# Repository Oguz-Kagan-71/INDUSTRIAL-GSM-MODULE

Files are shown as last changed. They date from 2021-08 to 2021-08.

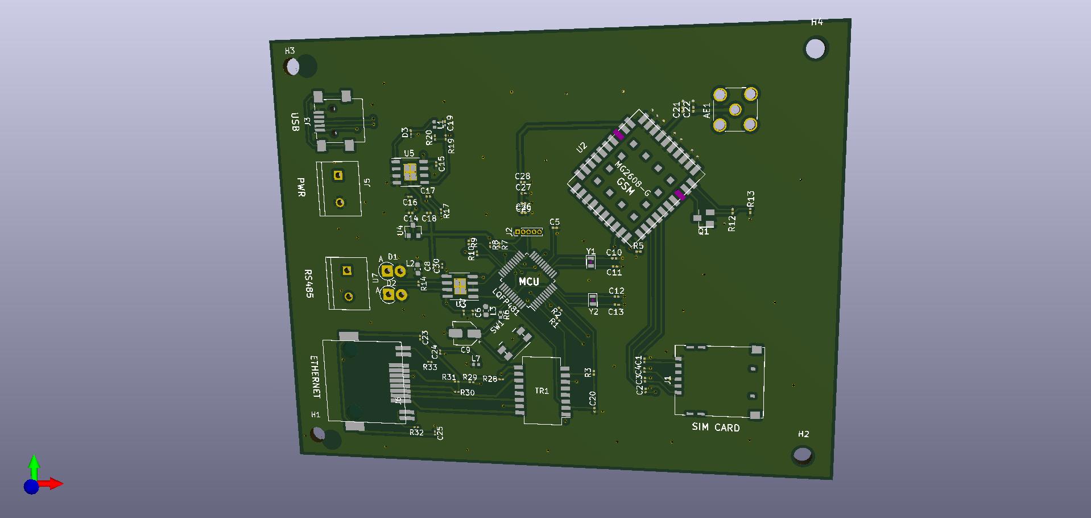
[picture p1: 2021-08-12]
gsm modem.jpg

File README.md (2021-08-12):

# INDUSTRIAL-GSM-MODULE
**PROJE KAZANIMLARI**
- Farklı amaca hizmet eden modüllerin datasheetini okuma
- Projeye uygun modül ve komponent seçimi
- Beslemelerde koruma amaçlı kullanılan kapasitör, endüktör, tvs diyot vb komponentlerin kullanımı
- PCB design edilen programda çoklu şematik pencere kullanımı, global label vb özelliklerin aktif kullanımı
- Kütüphanede olmayan komponentlerin şematik ve footprint kütüphanelerini datasheet bilgilerine göre oluşturup ekleme
- RS485 iletişim standartının ne olduğu ve hangi alanda kullanıldığı
- Transciever nedir ? Nasıl kullanılır ?
- Buck converter nedir ? Nasıl tasarlanır ?
- Yüksek voltaj kullanılan bir projede tasarım nasıl olmalıdır ? Regüle edilirken kullanılan komponentler nasıl konumlandırılmalıdır ?
- Konnektörler nasıl konumlandırılmalıdır ?
- Bağlantı kalınlıkları nasıl olmalıdır ?
- Anten bağlantısı nasıl olmalıdır ?
- Haberleşme bağlantıları nasıl olmalıdır ?
- GSM modülü nasıl çalışır ? Hangi amaca hizmet eder ?
- Modbus protokolü nedir ? Diğer haberleşme türlerinden farkı nedir ?
- 
-

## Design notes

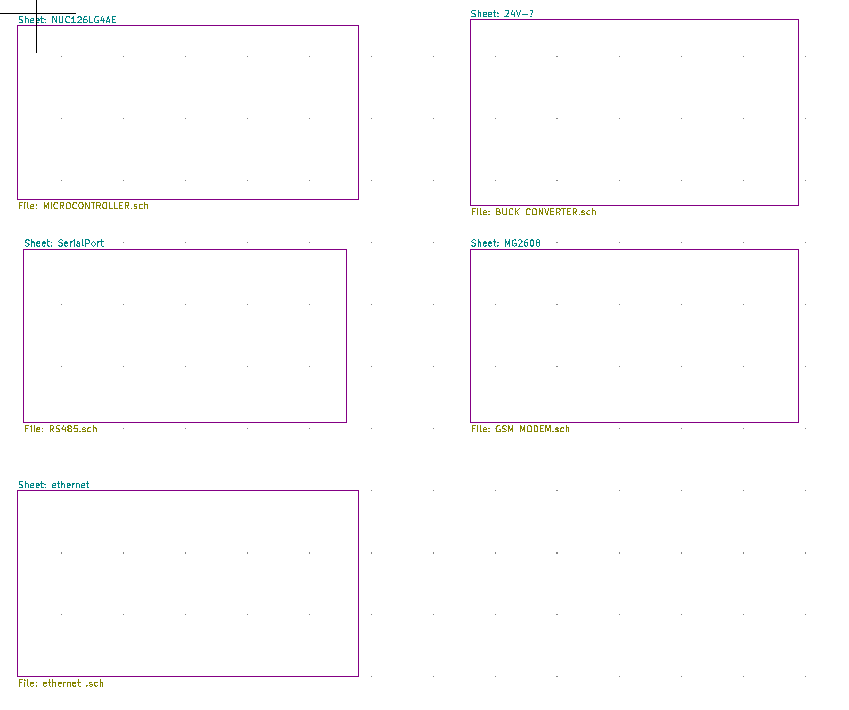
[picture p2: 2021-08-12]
Schematic.PNG

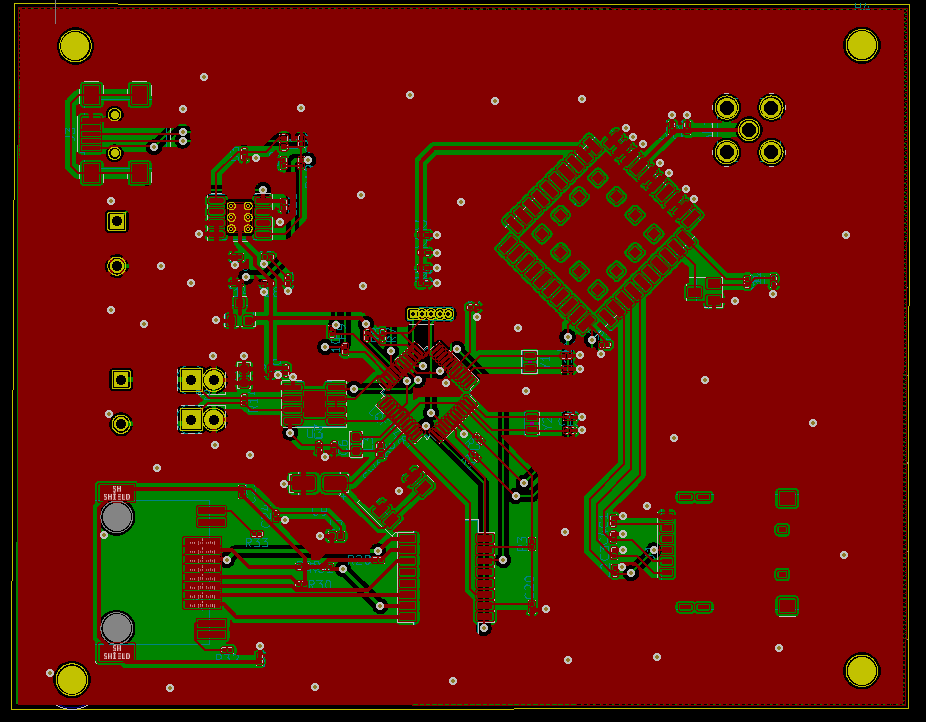
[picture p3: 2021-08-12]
gsm-pcb.PNG

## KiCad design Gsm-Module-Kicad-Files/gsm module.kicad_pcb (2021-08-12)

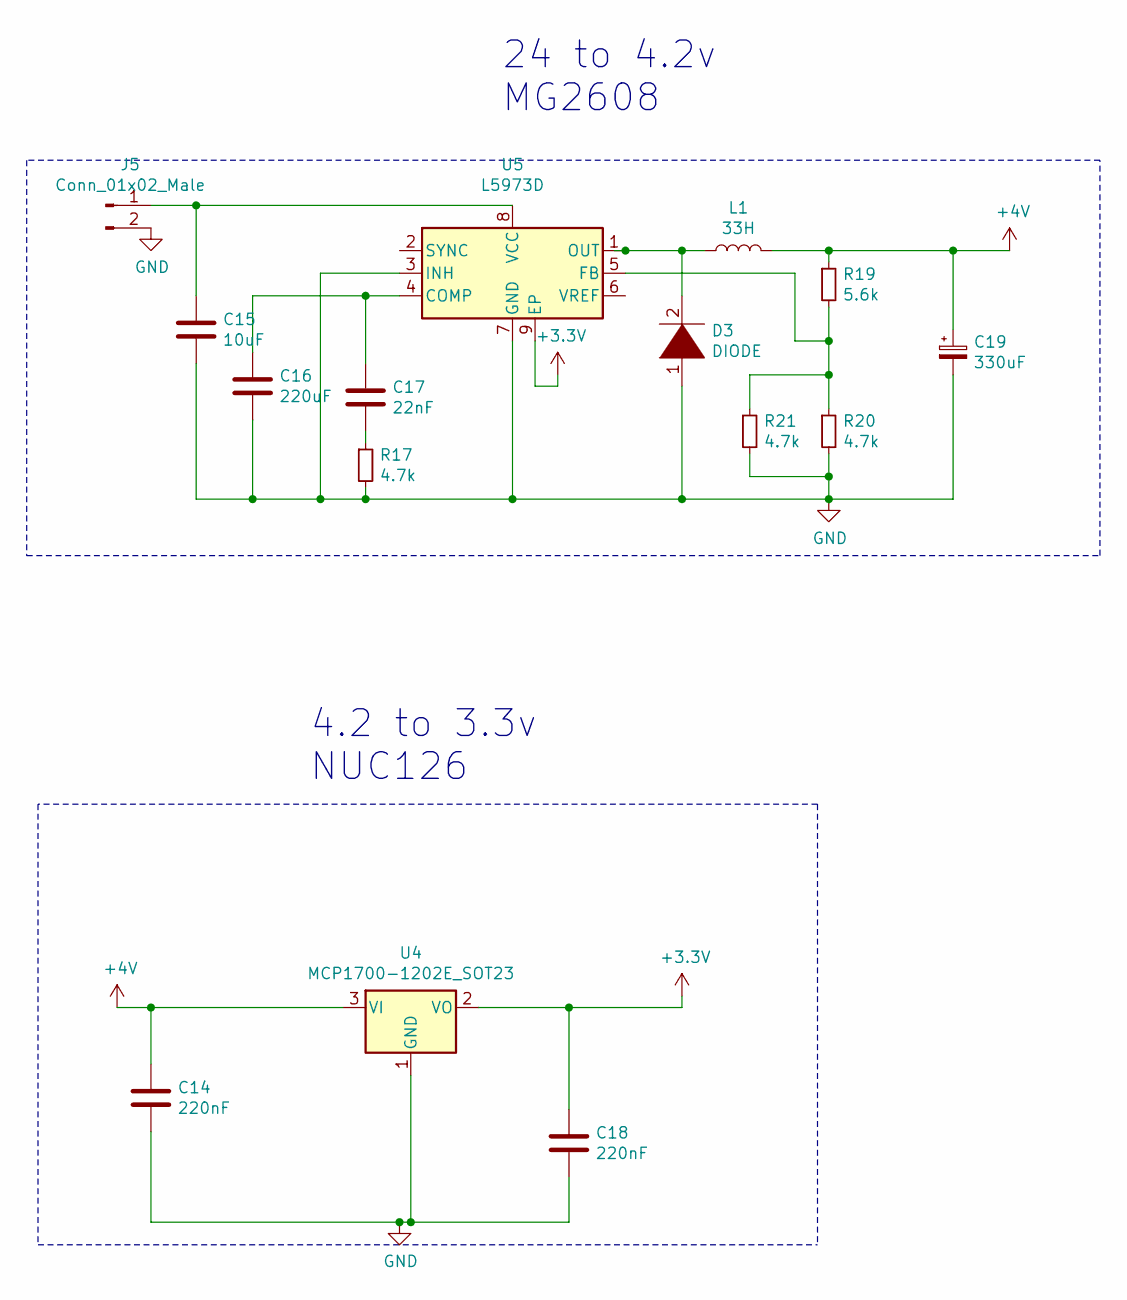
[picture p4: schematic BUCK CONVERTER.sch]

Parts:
C14, C18: 220nF; C_0201_0603Metric
C15: 10uF; C_0201_0603Metric
C16: 220uF; C_0201_0603Metric
C17: 22nF; C_0201_0603Metric
C19: 330uF; C_0201_0603Metric
D3: DIODE; D_0201_0603Metric
J5: Conn_01x02_Male; TE_282837-2
L1: 33H; L_0402_1005Metric
R17, R20, R21: 4.7k; R_0201_0603Metric
R19: 5.6k; R_0201_0603Metric
U4: MCP1700-1202E_SOT23; SOT-23
U5: L5973D; HSOP-8-1EP_3.9x4.9mm_P1.27mm_EP2.41x3.1mm_ThermalVias

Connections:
+3V3: C18.1, U4.2 (VO), U5.9 (EP); also elsewhere on the board
+4V: C14.1, C19.1, L1.2, R19.1, U4.3 (VI); also elsewhere on the board
GND: C14.2, C15.2, C16.2, C18.2, C19.2, D3.1 (K), J5.2, R17.2, R20.2, R21.2, U4.1 (GND), U5.3 (INH), U5.7 (GND); also elsewhere on the board
unnamed: C15.1, J5.1, U5.8 (VCC)
unnamed: C16.1, C17.1, U5.4 (COMP)
unnamed: C17.2, R17.1
unnamed: D3.2 (A), L1.1, U5.1 (OUT)
unnamed: R19.2, R20.1, R21.1, U5.5 (FB)

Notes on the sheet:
24 to 4.2v MG2608
4.2 to 3.3v NUC126

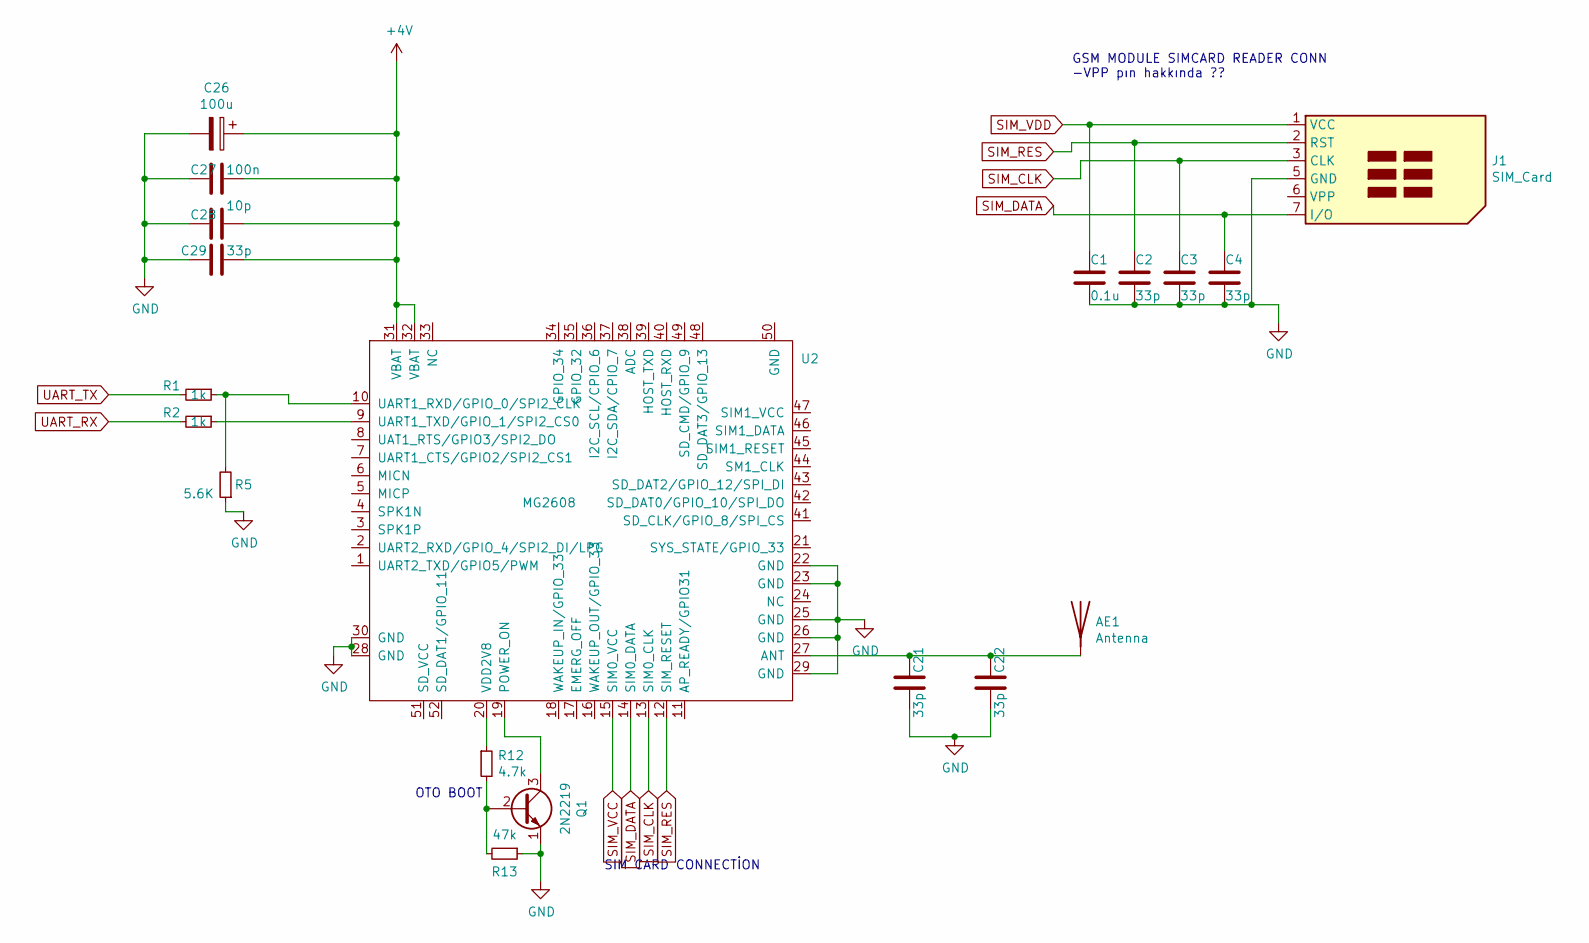
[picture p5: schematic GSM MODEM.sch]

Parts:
AE1: Antenna; SMA_Amphenol_132291_Vertical
C1: 0.1u; C_0201_0603Metric
C2, C3, C4, C21, C22, C29: 33p; C_0201_0603Metric
C26: 100u; C_0201_0603Metric
C27: 100n; C_0201_0603Metric
C28: 10p; C_0201_0603Metric
J1: SIM_Card; microSIM_JAE_SF53S006VCBR2000
Q1: 2N2219; SuperSOT-3
R1, R2: 1k; R_0201_0603Metric
R5: 5.6K; R_0201_0603Metric
R12: 4.7k; R_0201_0603Metric
R13: 47k; R_0201_0603Metric
U2: MG2608; MG2608-G

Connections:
+4V: C26.1, C27.1, C28.1, C29.2, U2.31 (VBAT), U2.32 (VBAT); also elsewhere on the board
GND: C1.2, C2.2, C3.2, C4.2, C21.2, C22.2, C26.2, C27.2, C28.2, C29.1, J1.5 (GND), Q1.1 (E), R5.1, R13.1, U2.22 (GND), U2.23 (GND), U2.25 (GND), U2.26 (GND), U2.28 (GND), U2.29 (GND), U2.30 (GND); also elsewhere on the board
unnamed: AE1.1, C21.1, C22.1, U2.27 (ANT)
unnamed: Q1.2 (B), R12.2, R13.2
unnamed: Q1.3 (C), U2.19 (POWER_ON)
unnamed: R1.1, R5.2, U2.10 (UART1_RXD/GPIO_0/SPI2_CLK)
unnamed: R2.1, U2.9 (UART1_TXD/GPIO_1/SPI2_CS0)
unnamed: R12.1, U2.20 (VDD2V8)
SIM_CLK: C3.1, J1.3 (CLK), U2.13 (SIM0_CLK)
SIM_DATA: C4.1, J1.7 (I/O), U2.14 (SIM0_DATA)
SIM_RES: C2.1, J1.2 (RST), U2.12 (SIM_RESET)
SIM_VCC: U2.15 (SIM0_VCC)
SIM_VDD: C1.1, J1.1 (VCC)
UART_RX: R2.2; also elsewhere on the board
UART_TX: R1.2; also elsewhere on the board

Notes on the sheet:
GSM MODULE SIMCARD READER CONN -VPP pın hakkında ??
SIM CARD CONNECTİON
OTO BOOT

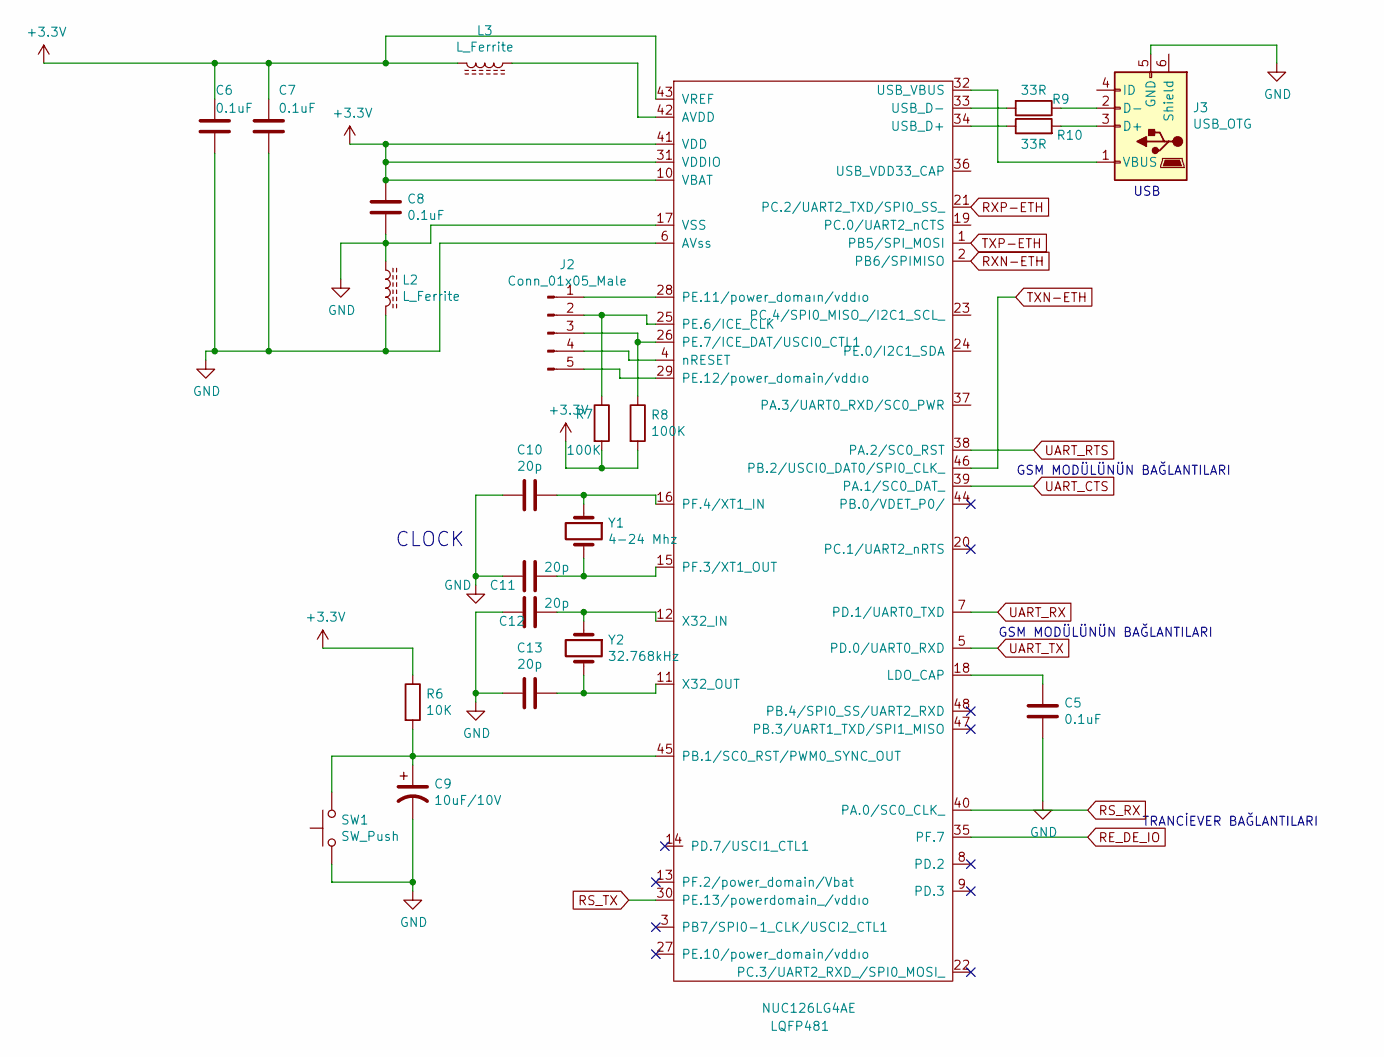
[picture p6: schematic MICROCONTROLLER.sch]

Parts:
C5, C6, C7, C8: 0.1uF; C_0201_0603Metric
C9: 10uF/10V; CP_Elec_4x3
C10, C11, C12, C13: 20p; C_0201_0603Metric
J2: Conn_01x05_Male; PinHeader_1x05_P1.00mm_Vertical
J3: USB_OTG; USB_Mini-B_Lumberg_2486_01_Horizontal
L2, L3: L_Ferrite; L_0603_1608Metric
LQFP481: NUC126LG4AE; LQFP-48_7x7mm_P0.5mm
R6: 10K; R_0402_1005Metric
R7, R8: 100K; R_0201_0603Metric
R9, R10: 33R; R_0201_0603Metric
SW1: SW_Push; Panasonic_EVQPUJ_EVQPUA
Y1: 4-24 Mhz; Crystal_SMD_2012-2Pin_2.0x1.2mm
Y2: 32.768kHz; Crystal_SMD_2012-2Pin_2.0x1.2mm

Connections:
+3V3: C6.1, C7.1, C8.2, L3.2, LQFP481.10 (VBAT), LQFP481.31 (VDDIO), LQFP481.41 (VDD), LQFP481.43 (VREF), R6.1, R7.2, R8.2; also elsewhere on the board
GND: C5.2, C6.2, C7.2, C8.1, C9.2, C10.2, C11.2, C12.2, C13.2, J3.5 (GND), L2.1, L2.2, LQFP481.6 (AVss), LQFP481.17 (VSS), SW1.1; also elsewhere on the board
unnamed: C5.1, LQFP481.18 (LDO_CAP)
unnamed: C9.1, LQFP481.45 (PB.1/SC0_RST/PWM0_SYNC_OUT), R6.2, SW1.2
unnamed: C10.1, LQFP481.16 (PF.4/XT1_IN), Y1.1
unnamed: C11.1, LQFP481.15 (PF.3/XT1_OUT), Y1.2
unnamed: C12.1, LQFP481.12 (X32_IN), Y2.1
unnamed: C13.1, LQFP481.11 (X32_OUT), Y2.2
unnamed: J2.1, LQFP481.28 (PE.11/power_domaın/vddıo)
unnamed: J2.2, LQFP481.25 (PE.6/ICE_CLK), R7.1
unnamed: J2.3, LQFP481.26 (PE.7/ICE_DAT/USCI0_CTL1), R8.1
unnamed: J2.4, LQFP481.4 (nRESET)
unnamed: J2.5, LQFP481.29 (PE.12/power_domain/vddıo)
unnamed: J3.1 (VBUS), LQFP481.32 (USB_VBUS)
unnamed: J3.2 (D-), R9.1
unnamed: J3.3 (D+), R10.2
unnamed: L3.1, LQFP481.42 (AVDD)
unnamed: LQFP481.33 (USB_D-), R9.2
unnamed: LQFP481.34 (USB_D+), R10.1
RE_DE_IO: LQFP481.35 (PF.7); also elsewhere on the board
RS_RX: LQFP481.40 (PA.0/SC0_CLK_); also elsewhere on the board
RS_TX: LQFP481.30 (PE.13/powerdomain_/vddıo); also elsewhere on the board
RXN-ETH: LQFP481.2 (PB6/SPIMISO); also elsewhere on the board
RXP-ETH: LQFP481.21 (PC.2/UART2_TXD/SPI0_SS_); also elsewhere on the board
TXN-ETH: LQFP481.46 (PB.2/USCI0_DAT0/SPI0_CLK_); also elsewhere on the board
TXP-ETH: LQFP481.1 (PB5/SPI_MOSI); also elsewhere on the board
UART_CTS: LQFP481.39 (PA.1/SC0_DAT_)
UART_RTS: LQFP481.38 (PA.2/SC0_RST)
UART_RX: LQFP481.7 (PD.1/UART0_TXD); also elsewhere on the board
UART_TX: LQFP481.5 (PD.0/UART0_RXD); also elsewhere on the board

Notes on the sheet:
CLOCK
USB
GSM MODÜLÜNÜN BAĞLANTILARI
TRANCİEVER BAĞLANTILARI

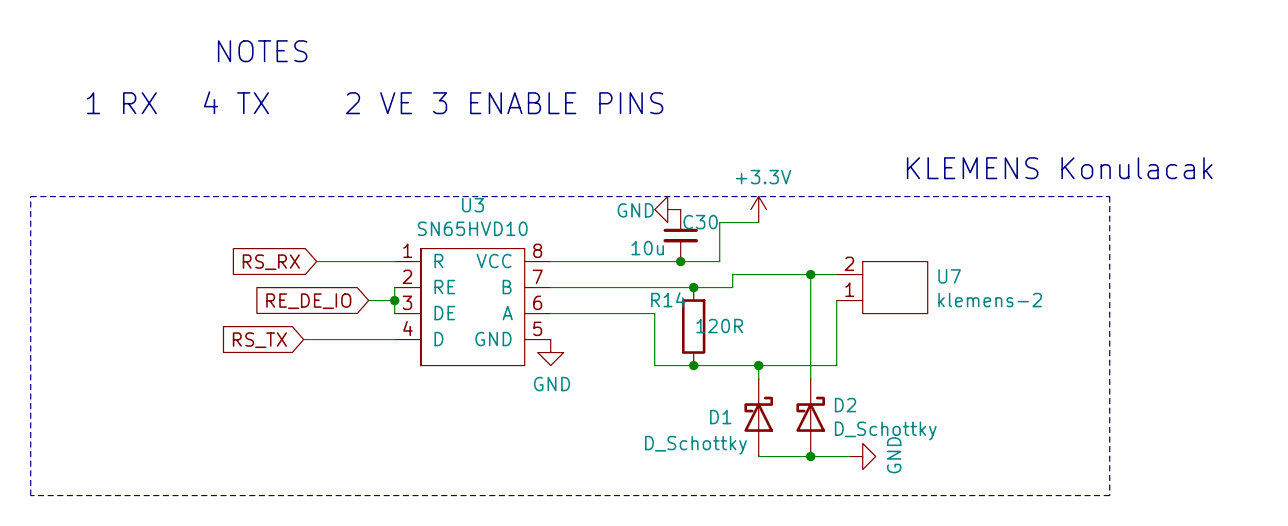
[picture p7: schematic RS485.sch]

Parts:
C30: 10u; C_0201_0603Metric
D1, D2: D_Schottky; D_DO-41_SOD81_P2.54mm_Vertical_AnodeUp
R14: 120R; R_0201_0603Metric
U3: SN65HVD10; SOIC-8-1EP_3.9x4.9mm_P1.27mm_EP2.29x3mm
U7: klemens-2; TE_282837-2

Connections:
+3V3: C30.2, U3.8 (VCC); also elsewhere on the board
GND: C30.1, D1.2 (A), D2.2 (A), U3.5 (GND); also elsewhere on the board
unnamed: D1.1 (K), R14.1, U3.6 (A), U7.1
unnamed: D2.1 (K), R14.2, U3.7 (B), U7.2
RE_DE_IO: U3.2 (RE), U3.3 (DE); also elsewhere on the board
RS_RX: U3.1 (R); also elsewhere on the board
RS_TX: U3.4 (D); also elsewhere on the board

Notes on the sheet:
1 RX
4 TX
2 VE 3 ENABLE PINS
NOTES
KLEMENS Konulacak

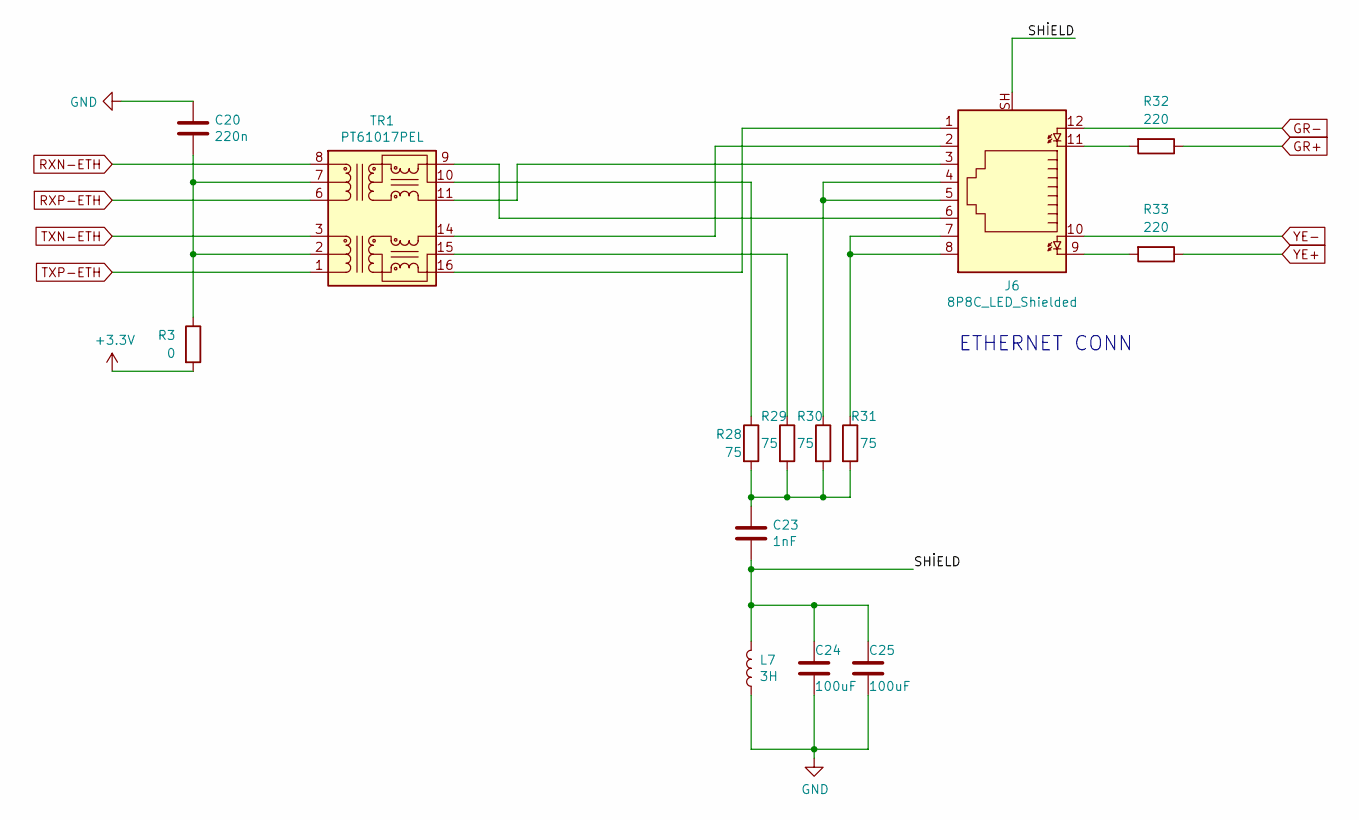
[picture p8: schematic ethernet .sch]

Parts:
C20: 220n; C_0201_0603Metric
C23: 1nF; C_0201_0603Metric
C24, C25: 100uF; C_0201_0603Metric
J6: 8P8C_LED_Shielded; Würth_RJ45_SMD
L7: 3H; L_0402_1005Metric
R3: 0; R_0201_0603Metric
R28, R29, R30, R31: 75; R_0201_0603Metric
R32, R33: 220; R_0201_0603Metric
TR1: PT61017PEL; Transformer_Ethernet_Bourns_PT61017PEL

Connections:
+3V3: R3.2; also elsewhere on the board
/ethernet/SHİELD: C23.1, C24.2, C25.2, J6.SH, L7.2
GND: C20.1, C24.1, C25.1, L7.1; also elsewhere on the board
GR+: R32.1
GR-: J6.12
unnamed: C20.2, R3.1, TR1.2 (C_TD), TR1.7 (C_RD)
unnamed: C23.2, R28.2, R29.2, R30.2, R31.2
unnamed: J6.1, TR1.16 (TX+)
unnamed: J6.2, TR1.14 (TX-)
unnamed: J6.3, TR1.11 (RX+)
unnamed: J6.4, J6.5, R30.1
unnamed: J6.6, TR1.9 (RX-)
unnamed: J6.7, J6.8, R31.1
unnamed: J6.9, R33.2
unnamed: J6.11, R32.2
unnamed: R28.1, TR1.10 (C_RX)
unnamed: R29.1, TR1.15 (C_TX)
RXN-ETH: TR1.8 (RD-); also elsewhere on the board
RXP-ETH: TR1.6 (RD+); also elsewhere on the board
TXN-ETH: TR1.3 (TD-); also elsewhere on the board
TXP-ETH: TR1.1 (TD+); also elsewhere on the board
YE+: R33.1
YE-: J6.10

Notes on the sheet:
ETHERNET CONN

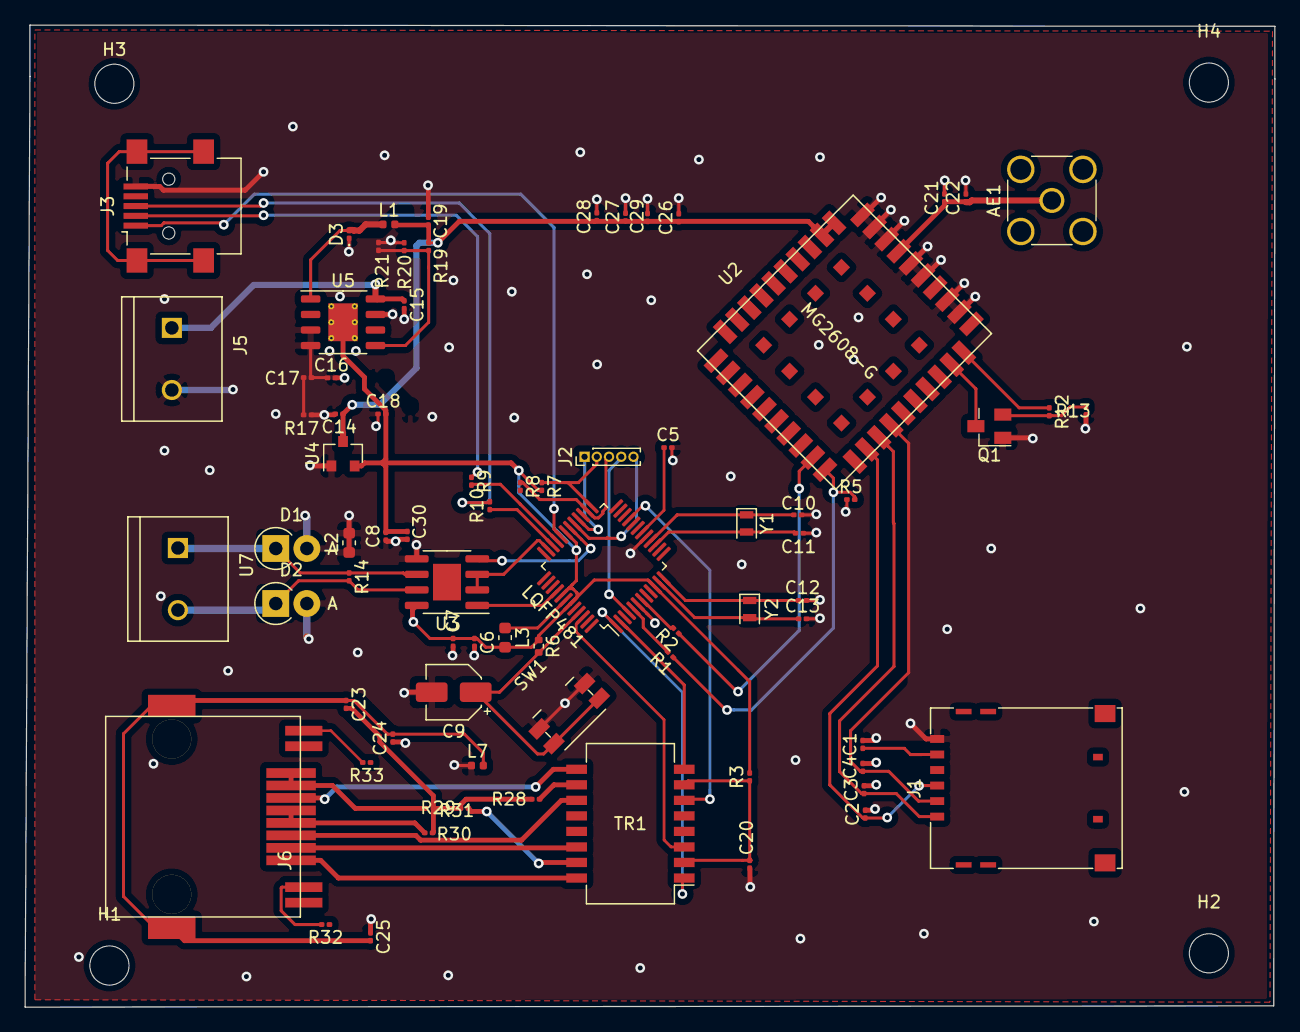
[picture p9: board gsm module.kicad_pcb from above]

Board: 2 copper layers, 102.2 x 80.3 mm, 80 parts (0 on the bottom side), 59 nets.

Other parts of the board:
H1, H2, H3, H4: MountingHole; MountingHole_3.2mm_M3

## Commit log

2021-08-04 last version
    [ARES485.sch, BUCK CONVERTER FOR MG2608.sch, BUCK CONVERTER.sch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]
2021-08-06 Update gsm module.kicad_pcb
    PCB measure edit
    [gsm module.kicad_pcb]
